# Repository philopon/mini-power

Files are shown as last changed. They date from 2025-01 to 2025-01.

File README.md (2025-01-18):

# mini-power

mini power manager for PC

<p>
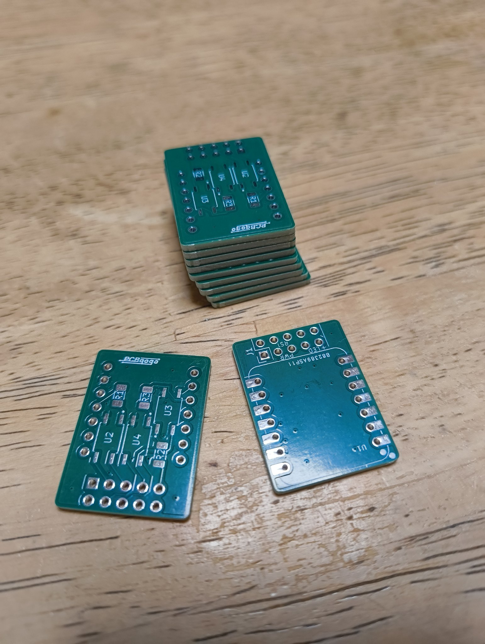
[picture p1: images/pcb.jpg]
  
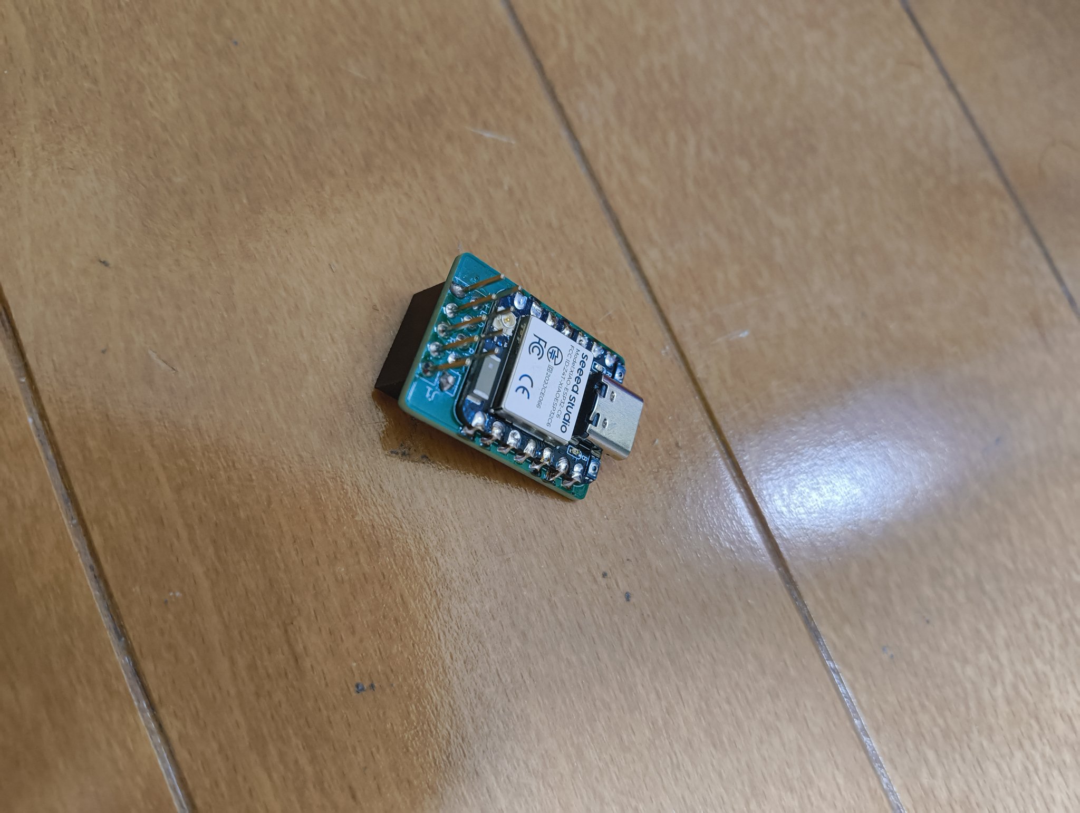
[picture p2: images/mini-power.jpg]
  
</p>
<p>
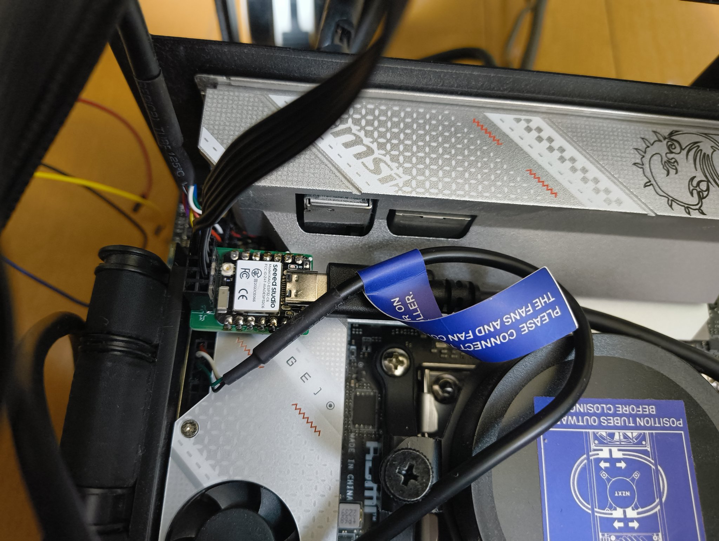
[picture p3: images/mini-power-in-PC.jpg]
  
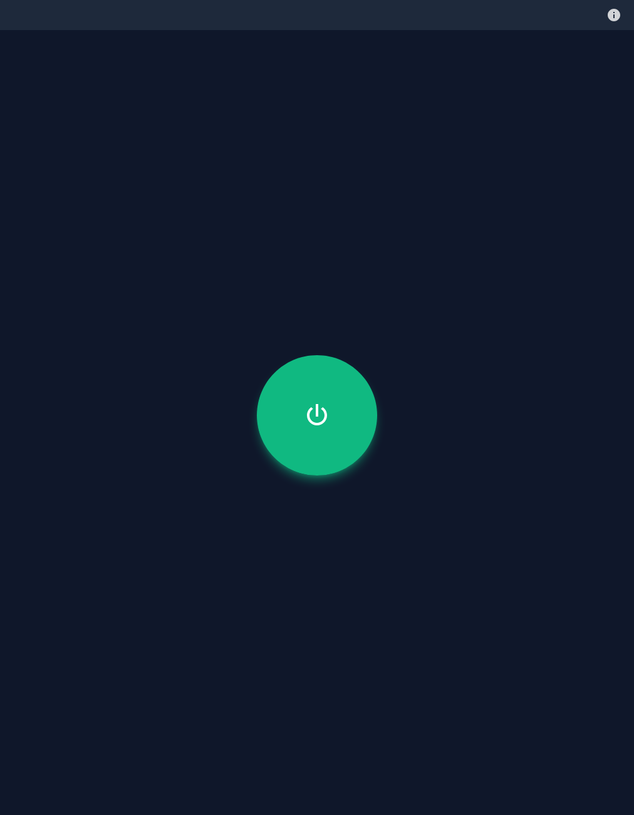
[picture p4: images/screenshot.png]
  
</p>

## PCB

### KiCad dependencies

- [TLP172AM](https://www.digikey.jp/ja/models/6679819)
- [SparkFun-Connector](https://github.com/sparkfun/SparkFun-KiCad-Libraries/blob/main/Symbols/SparkFun-Connector.kicad_sym)
- [Seeed Series Kicad files](https://wiki.seeedstudio.com/SeeedStudio_XIAO_Series_Introduction/#seeed-series-kicad-files)

### BOM

- U1: [Seeed Studio XIAO ESP32C6](https://akizukidenshi.com/catalog/g/g129481/) x 1
- U2-U4: [TLP172AM](https://akizukidenshi.com/catalog/g/g116065/) x 3
- J1: [1x5 pin socket](https://akizukidenshi.com/catalog/g/g110397/) x 2
- 1206 SMD resistor
  - R1,R3: 200R x 2
  - R2: 330R x 1
- [PCB](gerber.zip) x 1

## write firmware

```
$ cp src/config.cpp.template src/config.cpp
# Edit src/config.cpp

# install npm packages
$ cd frontend
$ pnpm install

# build and send firmware using platformio

```

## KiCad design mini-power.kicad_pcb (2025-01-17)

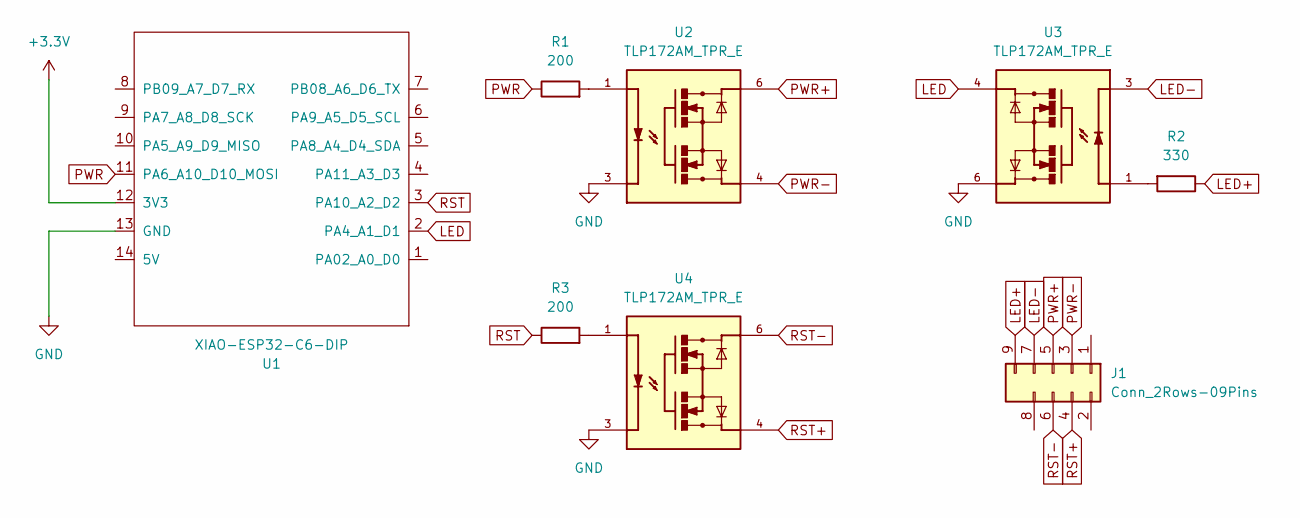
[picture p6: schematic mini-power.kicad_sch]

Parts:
J1: Conn_2Rows-09Pins; PinHeader_2x05_P2.54mm_Vertical
R1, R3: 200; R_1206_3216Metric
R2: 330; R_1206_3216Metric
U1: XIAO-ESP32-C6-DIP; XIAO-ESP32C6-DIP
U2, U3, U4: TLP172AM_TPR_E; SOIC254P700X220-4N; PARTREV 5.0

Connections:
+3.3V: U1.12 (3V3)
GND: U1.13 (GND), U2.3, U3.6, U4.3
LED: U1.2 (PA4_A1_D1), U3.4
LED+: J1.9, R2.1
LED-: J1.7, U3.3
unnamed: R1.2, U2.1
unnamed: R2.2, U3.1
unnamed: R3.2, U4.1
PWR: R1.1, U1.11 (PA6_A10_D10_MOSI)
PWR+: J1.5, U2.6
PWR-: J1.3, U2.4
RST: R3.1, U1.3 (PA10_A2_D2)
RST+: J1.4, U4.4
RST-: J1.6, U4.6

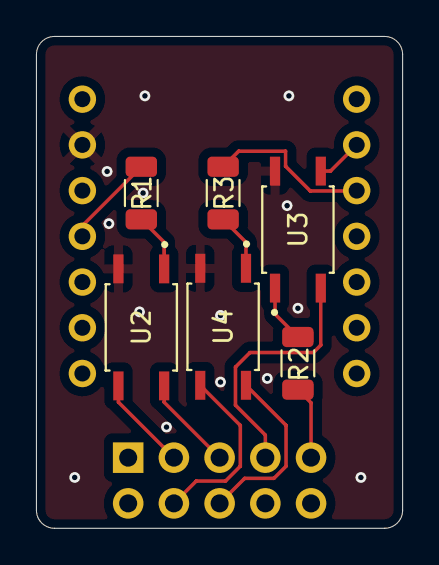
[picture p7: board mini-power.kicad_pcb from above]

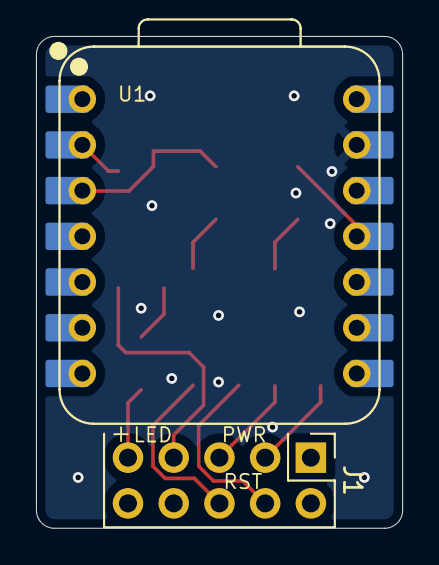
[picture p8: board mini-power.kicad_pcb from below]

Board: 2 copper layers, 20.3 x 27.3 mm, 8 parts (2 on the bottom side), 13 nets.

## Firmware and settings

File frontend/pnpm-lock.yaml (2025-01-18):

lockfileVersion: '9.0'

settings:
  autoInstallPeers: true
  excludeLinksFromLockfile: false

importers:

  .:
    devDependencies:
      '@iconify/svelte':
        specifier: ^4.2.0
        version: 4.2.0(svelte@5.19.0)
      '@sveltejs/adapter-static':
        specifier: ^3.0.8
        version: 3.0.8(@sveltejs/kit@2.16.0(@sveltejs/vite-plugin-svelte@4.0.4(svelte@5.19.0)(vite@5.4.11))(svelte@5.19.0)(vite@5.4.11))
      '@sveltejs/kit':
        specifier: ^2.0.0
        version: 2.16.0(@sveltejs/vite-plugin-svelte@4.0.4(svelte@5.19.0)(vite@5.4.11))(svelte@5.19.0)(vite@5.4.11)
      '@sveltejs/vite-plugin-svelte':
        specifier: ^4.0.0
        version: 4.0.4(svelte@5.19.0)(vite@5.4.11)
      autoprefixer:
        specifier: ^10.4.20
        version: 10.4.20(postcss@8.5.1)
      prettier:
        specifier: ^3.3.2
        version: 3.4.2
      prettier-plugin-svelte:
        specifier: ^3.2.6
        version: 3.3.3(prettier@3.4.2)(svelte@5.19.0)
      svelte:
        specifier: ^5.0.0
        version: 5.19.0
      svelte-check:
        specifier: ^4.0.0
        version: 4.1.4(svelte@5.19.0)(typescript@5.7.3)
      svelteesp32:
        specifier: ^1.7.0
        version: 1.7.0
      tailwindcss:
        specifier: ^3.4.17
        version: 3.4.17
      typescript:
        specifier: ^5.0.0
        version: 5.7.3
      vite:
        specifier: ^5.4.11
        version: 5.4.11

packages:

  '@alloc/quick-lru@5.2.0':
    resolution: {integrity: sha512-UrcABB+4bUrFABwbluTIBErXwvbsU/V7TZWfmbgJfbkwiBuziS9gxdODUyuiecfdGQ85jglMW6juS3+z5TsKLw==}
    engines: {node: '>=10'}

  '@ampproject/remapping@2.3.0':
    resolution: {integrity: sha512-30iZtAPgz+LTIYoeivqYo853f02jBYSd5uGnGpkFV0M3xOt9aN73erkgYAmZU43x4VfqcnLxW9Kpg3R5LC4YYw==}
    engines: {node: '>=6.0.0'}

  '@esbuild/aix-ppc64@0.21.5':
    resolution: {integrity: sha512-1SDgH6ZSPTlggy1yI6+Dbkiz8xzpHJEVAlF/AM1tHPLsf5STom9rwtjE4hKAF20FfXXNTFqEYXyJNWh1GiZedQ==}
    engines: {node: '>=12'}
    cpu: [ppc64]
    os: [aix]

  '@esbuild/android-arm64@0.21.5':
    resolution: {integrity: sha512-c0uX9VAUBQ7dTDCjq+wdyGLowMdtR/GoC2U5IYk/7D1H1JYC0qseD7+11iMP2mRLN9RcCMRcjC4YMclCzGwS/A==}
    engines: {node: '>=12'}
    cpu: [arm64]
    os: [android]

  '@esbuild/android-arm@0.21.5':
    resolution: {integrity: sha512-vCPvzSjpPHEi1siZdlvAlsPxXl7WbOVUBBAowWug4rJHb68Ox8KualB+1ocNvT5fjv6wpkX6o/iEpbDrf68zcg==}
    engines: {node: '>=12'}
    cpu: [arm]
    os: [android]

  '@esbuild/android-x64@0.21.5':
    resolution: {integrity: sha512-D7aPRUUNHRBwHxzxRvp856rjUHRFW1SdQATKXH2hqA0kAZb1hKmi02OpYRacl0TxIGz/ZmXWlbZgjwWYaCakTA==}
    engines: {node: '>=12'}
    cpu: [x64]
    os: [android]

  '@esbuild/darwin-arm64@0.21.5':
    resolution: {integrity: sha512-DwqXqZyuk5AiWWf3UfLiRDJ5EDd49zg6O9wclZ7kUMv2WRFr4HKjXp/5t8JZ11QbQfUS6/cRCKGwYhtNAY88kQ==}
    engines: {node: '>=12'}
    cpu: [arm64]
    os: [darwin]

  '@esbuild/darwin-x64@0.21.5':
    resolution: {integrity: sha512-se/JjF8NlmKVG4kNIuyWMV/22ZaerB+qaSi5MdrXtd6R08kvs2qCN4C09miupktDitvh8jRFflwGFBQcxZRjbw==}
    engines: {node: '>=12'}
    cpu: [x64]
    os: [darwin]

  '@esbuild/freebsd-arm64@0.21.5':
    resolution: {integrity: sha512-5JcRxxRDUJLX8JXp/wcBCy3pENnCgBR9bN6JsY4OmhfUtIHe3ZW0mawA7+RDAcMLrMIZaf03NlQiX9DGyB8h4g==}
    engines: {node: '>=12'}
    cpu: [arm64]
    os: [freebsd]

  '@esbuild/freebsd-x64@0.21.5':
    resolution: {integrity: sha512-J95kNBj1zkbMXtHVH29bBriQygMXqoVQOQYA+ISs0/2l3T9/kj42ow2mpqerRBxDJnmkUDCaQT/dfNXWX/ZZCQ==}
    engines: {node: '>=12'}
    cpu: [x64]
    os: [freebsd]

  '@esbuild/linux-arm64@0.21.5':
    resolution: {integrity: sha512-ibKvmyYzKsBeX8d8I7MH/TMfWDXBF3db4qM6sy+7re0YXya+K1cem3on9XgdT2EQGMu4hQyZhan7TeQ8XkGp4Q==}
    engines: {node: '>=12'}
    cpu: [arm64]
    os: [linux]

  '@esbuild/linux-arm@0.21.5':
    resolution: {integrity: sha512-bPb5AHZtbeNGjCKVZ9UGqGwo8EUu4cLq68E95A53KlxAPRmUyYv2D6F0uUI65XisGOL1hBP5mTronbgo+0bFcA==}
    engines: {node: '>=12'}
    cpu: [arm]
    os: [linux]

  '@esbuild/linux-ia32@0.21.5':
    resolution: {integrity: sha512-YvjXDqLRqPDl2dvRODYmmhz4rPeVKYvppfGYKSNGdyZkA01046pLWyRKKI3ax8fbJoK5QbxblURkwK/MWY18Tg==}
    engines: {node: '>=12'}
    cpu: [ia32]
    os: [linux]

  '@esbuild/linux-loong64@0.21.5':
    resolution: {integrity: sha512-uHf1BmMG8qEvzdrzAqg2SIG/02+4/DHB6a9Kbya0XDvwDEKCoC8ZRWI5JJvNdUjtciBGFQ5PuBlpEOXQj+JQSg==}
    engines: {node: '>=12'}
    cpu: [loong64]
    os: [linux]

  '@esbuild/linux-mips64el@0.21.5':
    resolution: {integrity: sha512-IajOmO+KJK23bj52dFSNCMsz1QP1DqM6cwLUv3W1QwyxkyIWecfafnI555fvSGqEKwjMXVLokcV5ygHW5b3Jbg==}
    engines: {node: '>=12'}
    cpu: [mips64el]
    os: [linux]

  '@esbuild/linux-ppc64@0.21.5':
    resolution: {integrity: sha512-1hHV/Z4OEfMwpLO8rp7CvlhBDnjsC3CttJXIhBi+5Aj5r+MBvy4egg7wCbe//hSsT+RvDAG7s81tAvpL2XAE4w==}
    engines: {node: '>=12'}
    cpu: [ppc64]
    os: [linux]
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

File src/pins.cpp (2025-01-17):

#include <Arduino.h>
#include "./pins.hpp"
#include "./server.hpp"

bool *power_led_state = new bool;

void PowerLedChanged()
{
    bool state = !digitalRead(POWER_LED_PIN);
    *power_led_state = state;

    SendPowerLedChangedFromISR(state);
}

void InitializePins()
{
    pinMode(LED_BUILTIN, OUTPUT);
    digitalWrite(LED_BUILTIN, HIGH);

    pinMode(POWER_BUTTON_PIN, OUTPUT);
    digitalWrite(POWER_BUTTON_PIN, LOW);

    pinMode(RESET_BUTTON_PIN, OUTPUT);
    digitalWrite(RESET_BUTTON_PIN, LOW);

    pinMode(POWER_LED_PIN, INPUT_PULLUP);
    *power_led_state = !digitalRead(POWER_LED_PIN);
    attachInterrupt(POWER_LED_PIN, PowerLedChanged, CHANGE);
}
